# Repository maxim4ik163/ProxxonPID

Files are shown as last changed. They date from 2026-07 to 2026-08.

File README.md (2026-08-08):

# ProxxonPID

Модифицированная версия проекта AlexGyver [DrillPID2](https://github.com/AlexGyver/DrillPID2), адаптированная для **Proxxon Micromot 50/E**.

Проект предназначен для замены штатной платы управления Proxxon Micromot 50/E на собственную плату с функцией поддержания заданной скорости вращения двигателя.

## Основные изменения

* плата разработана с учётом конструкции Proxxon Micromot 50/E и изготавливается в домашних условиях на однослойном текстолите методом ЛУТ;
* изменены `MAX_TARGET_EMF` и `DIV_R2` с учётом питания от 20 В;
* используется родной потенциометр с выключателем;
* добавлен индикатор работы на D13;
* [3D-модель](3D_models/PD_trigger_holder.3mf) крепления PD-триггера;
* проект платы выполнен в Altium Designer.

## Фотографии

### Proxxon Micromot 50/E

<p align="center">
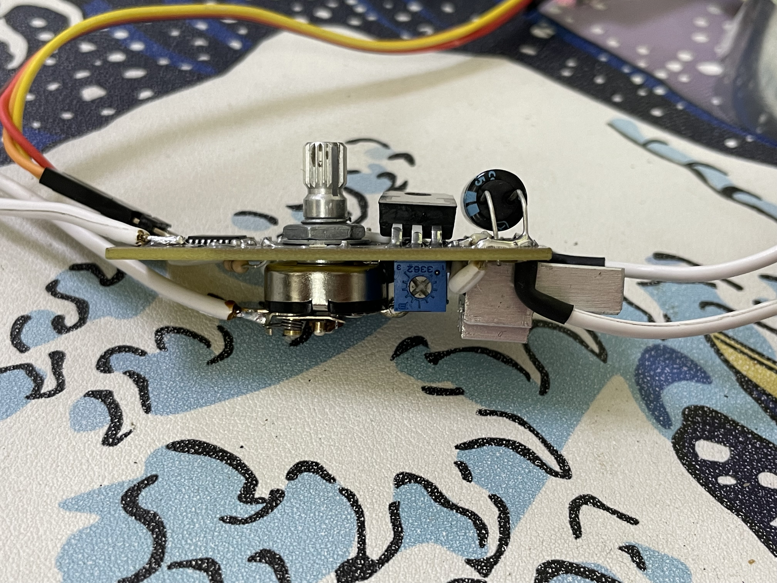
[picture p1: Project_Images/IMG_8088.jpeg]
  
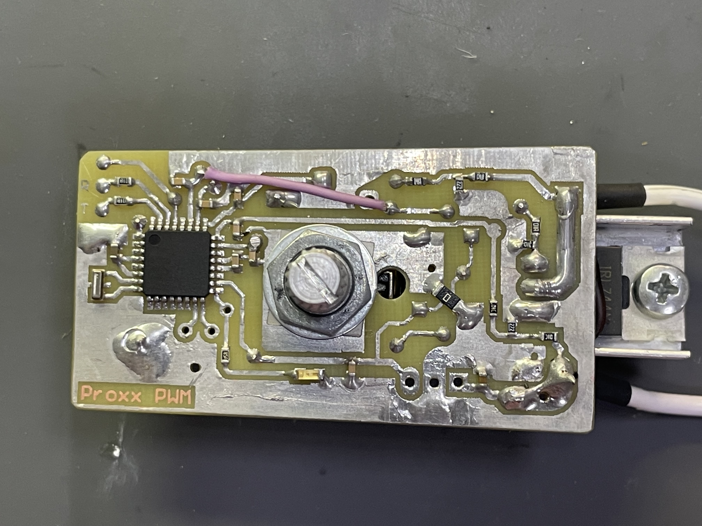
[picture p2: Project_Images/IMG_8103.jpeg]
  
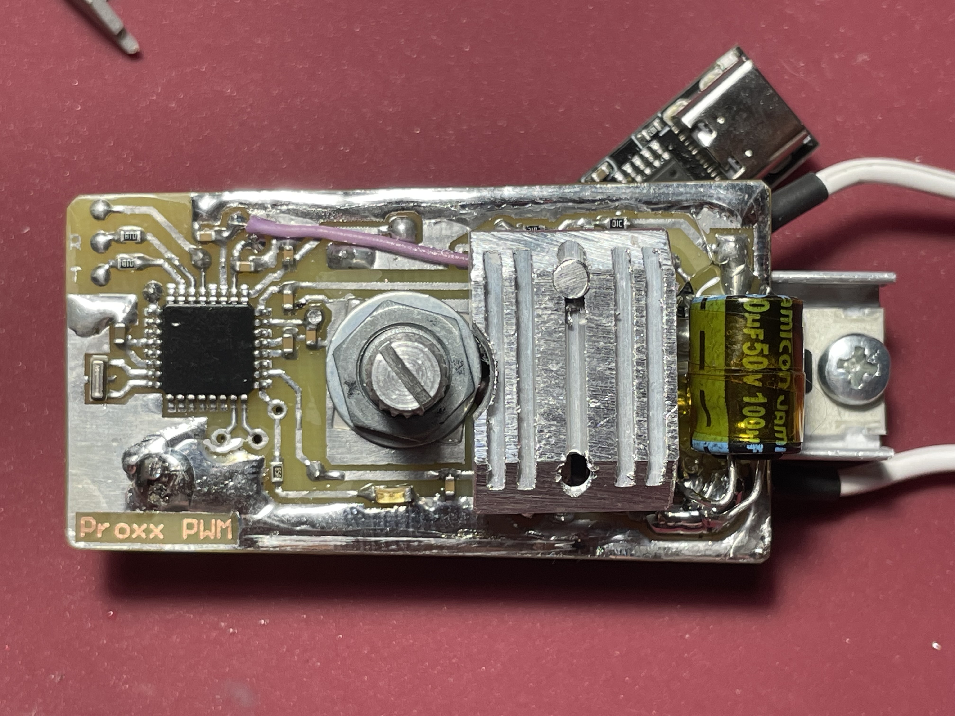
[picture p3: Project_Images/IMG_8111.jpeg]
  
</p>

<p align="center">
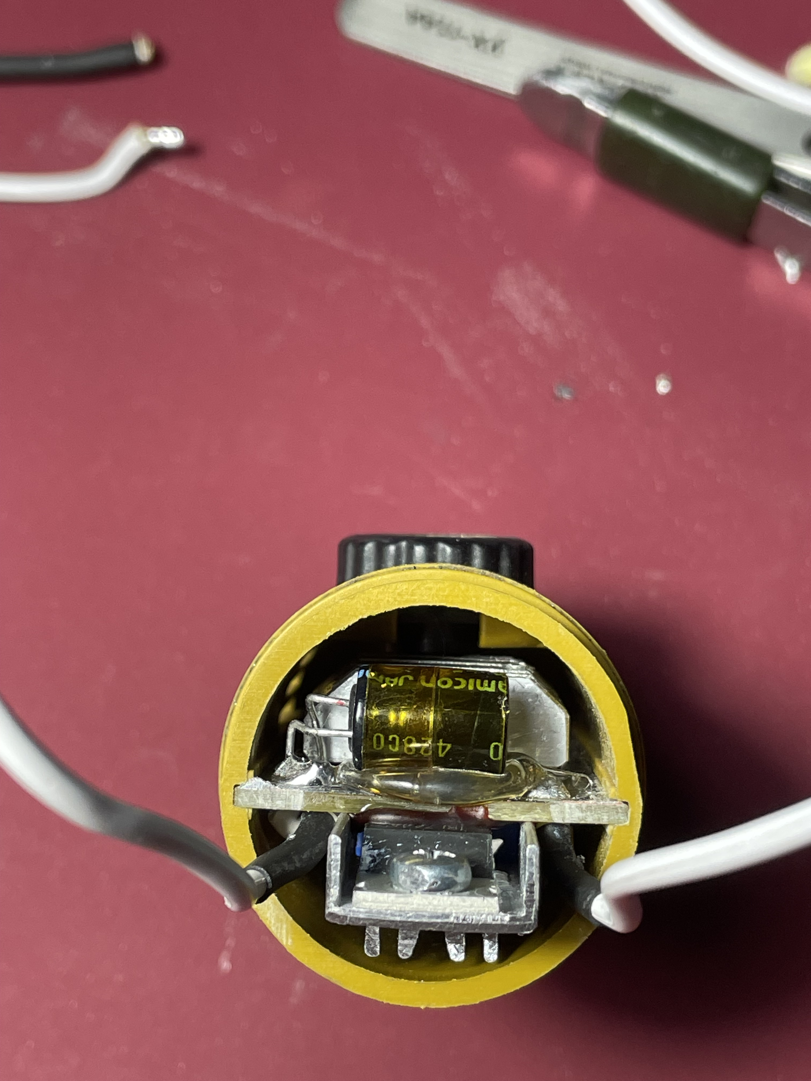
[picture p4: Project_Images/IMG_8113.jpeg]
  
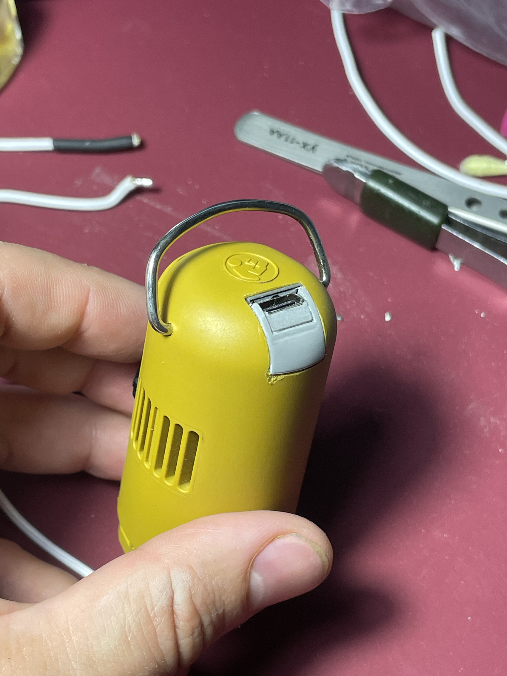
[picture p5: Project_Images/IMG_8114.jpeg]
  
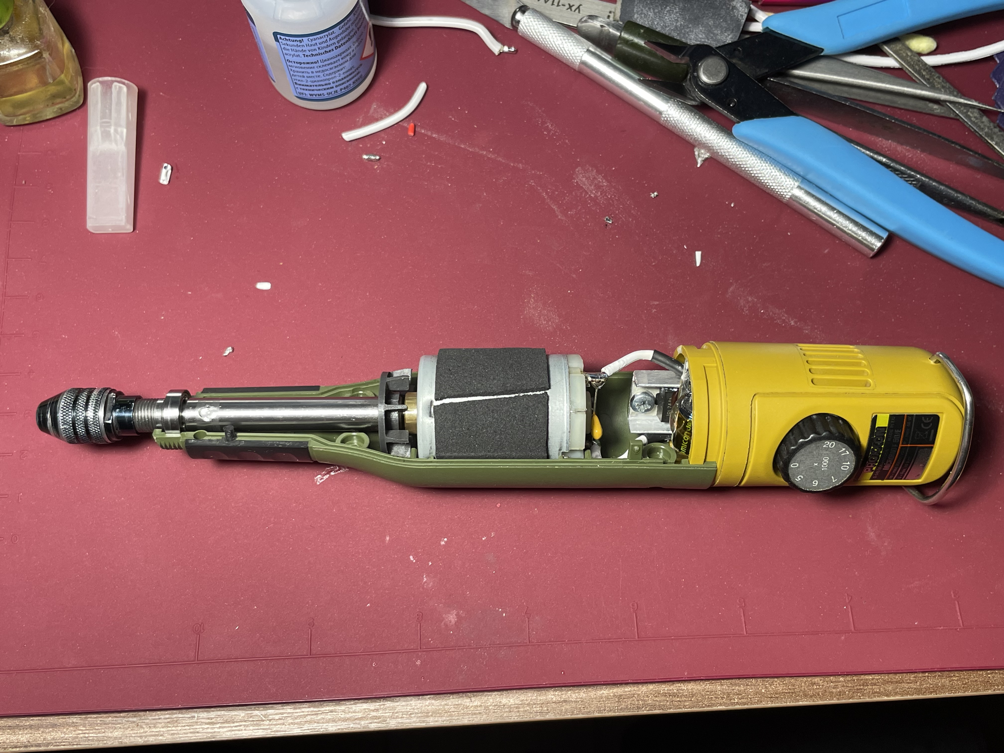
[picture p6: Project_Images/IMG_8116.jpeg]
  
</p>

### Штатная плата

<p align="center">
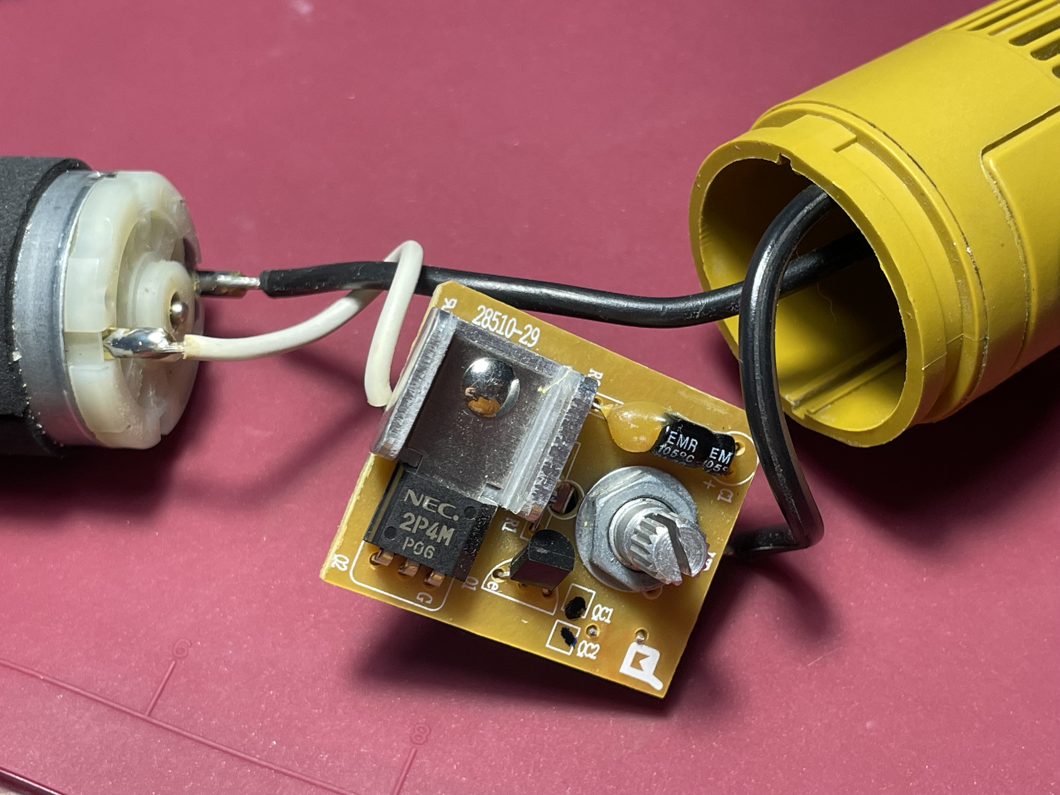
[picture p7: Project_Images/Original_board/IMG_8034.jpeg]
  
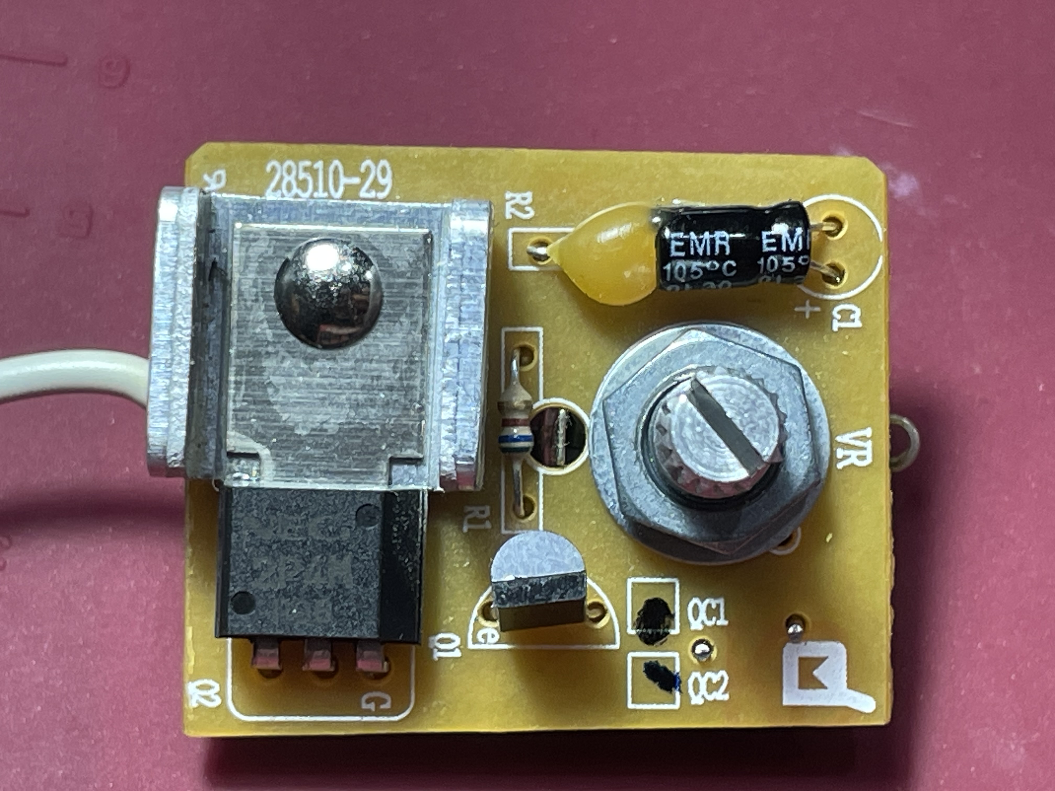
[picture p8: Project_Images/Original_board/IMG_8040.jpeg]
  
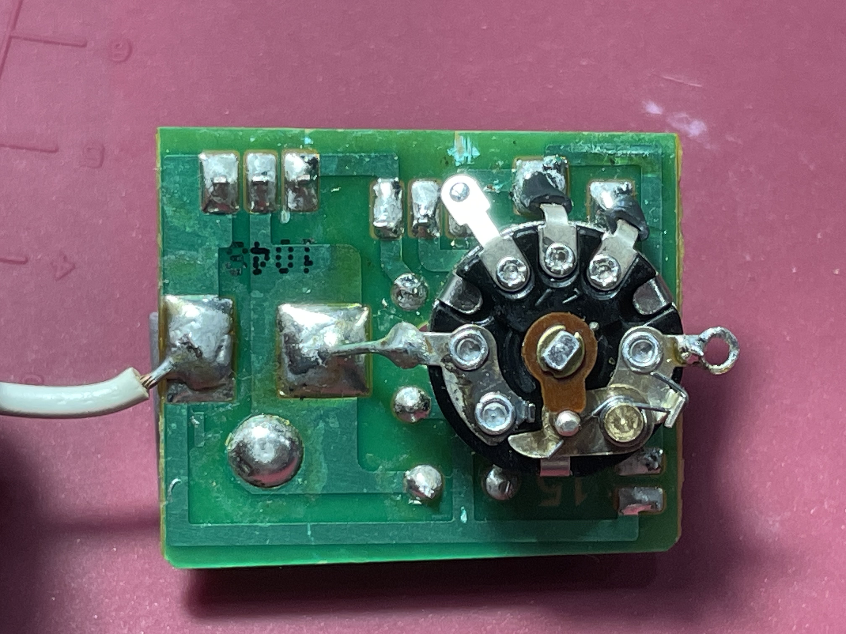
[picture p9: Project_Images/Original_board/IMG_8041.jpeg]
  
</p>

### PD-триггер

<p align="center">
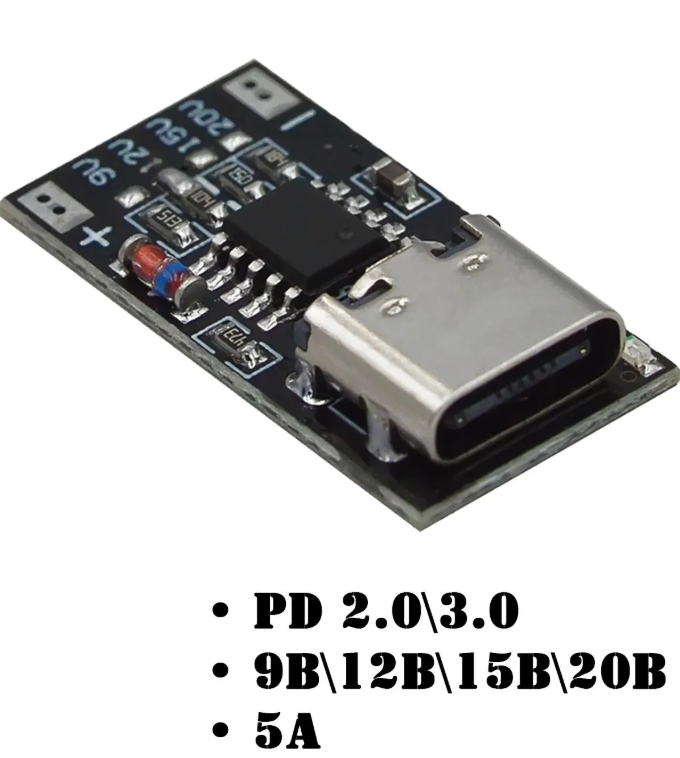
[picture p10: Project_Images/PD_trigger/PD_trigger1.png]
  
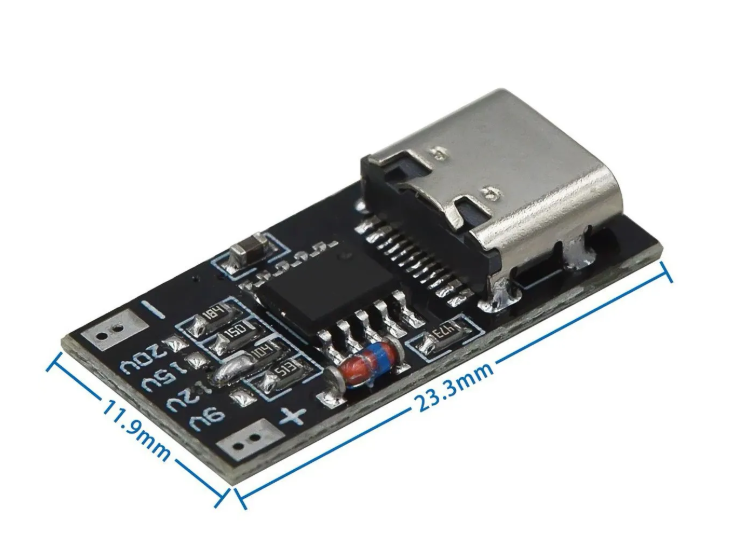
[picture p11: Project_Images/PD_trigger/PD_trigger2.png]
  
</p>

## Проект платы

Исходные файлы печатной платы находятся в каталоге [`PCB`](Altium_project/Proxxon_PWM_board).

Проект выполнен в **Altium Designer 25**.

## Прошивка

Прошивка для **Arduino Nano** находится в каталоге [`Firmware`](firmware/DrillPID2).

## Disclaimer

Проект предназначен для самостоятельного изготовления и модификации оборудования.

Использование проекта осуществляется на свой страх и риск. Автор не несёт ответственности за повреждение инструмента, электроники или иного оборудования в результате использования данной разработки.

---

# English

# ProxxonPID

A modified version of the AlexGyver [DrillPID2](https://github.com/AlexGyver/DrillPID2) project, adapted for the **Proxxon Micromot 50/E**.

The project is intended to replace the original control board of the Proxxon Micromot 50/E with a custom control board featuring **constant speed control**.

## Main Changes

* PCB designed specifically for the Proxxon Micromot 50/E and suitable for home manufacturing on single-sided PCB material using the toner transfer method;
* `MAX_TARGET_EMF` and `DIV_R2` values modified for a 20 V power supply;
* the original potentiometer with an integrated switch is retained;
* an operation indicator has been added to D13;
* [3D model](3D_models/PD_trigger_holder.3mf) of the PD trigger holder;
* PCB project designed in Altium Designer.

## Photos

### Proxxon Micromot 50/E

<p align="center">
  
  
  
</p>

<p align="center">
  
  
  
</p>

### Original Control Board

<p align="center">
  
  
  
</p>

### PD Trigger

<p align="center">
  
  
</p>

## PCB Project

The PCB source files are located in the [`PCB`](Altium_project/Proxxon_PWM_board) directory.

The project was designed using **Altium Designer 25**.

## Firmware

The **Arduino Nano** firmware is located in the [`Firmware`](firmware/DrillPID2) directory.

## Disclaimer

This project is intended for DIY manufacturing and modification of equipment.

Use this project at your own risk. The author is not responsible for any damage to the tool, electronics, or other equipment resulting from the use of this project.

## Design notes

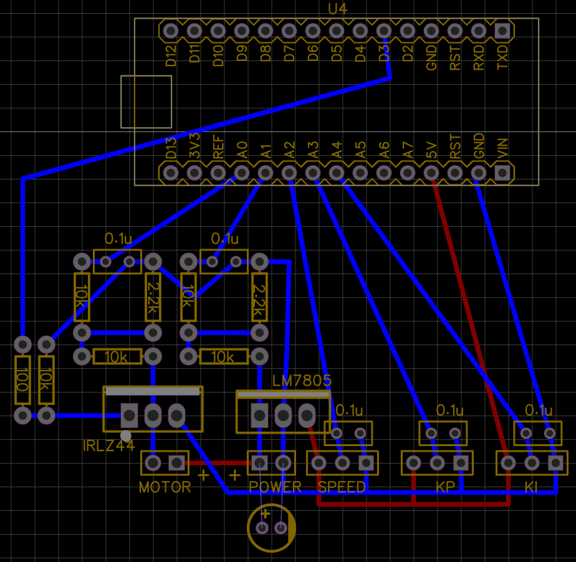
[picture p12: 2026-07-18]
scheme_and_LUTpcb/Original_board.png

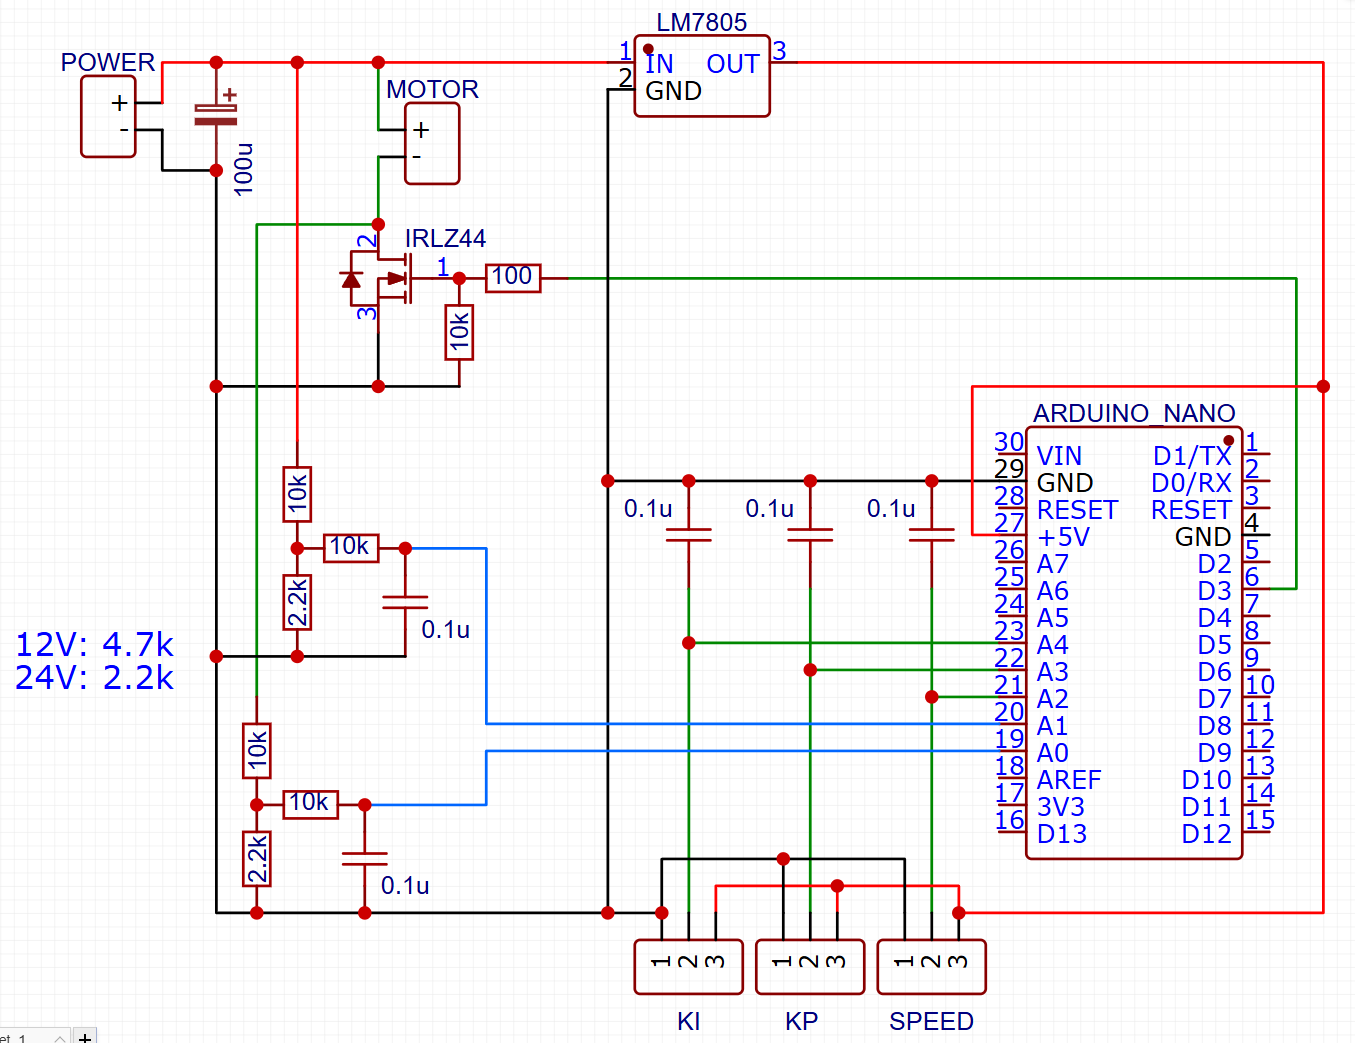
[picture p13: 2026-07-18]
scheme_and_LUTpcb/Original_scheme-eda.png

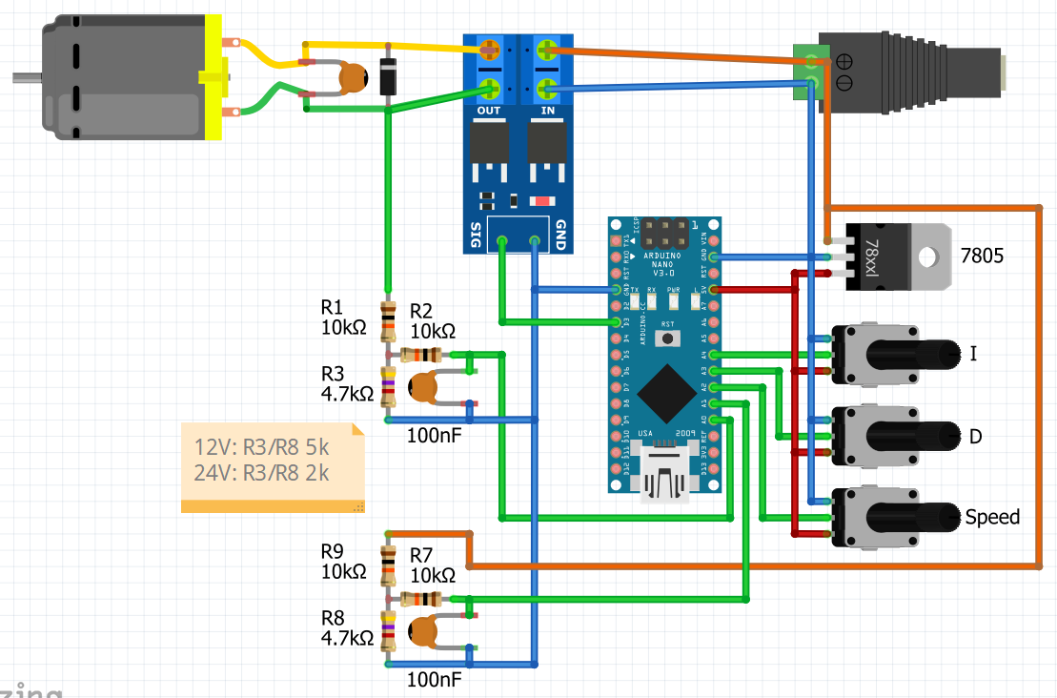
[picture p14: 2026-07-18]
scheme_and_LUTpcb/Original_scheme.png

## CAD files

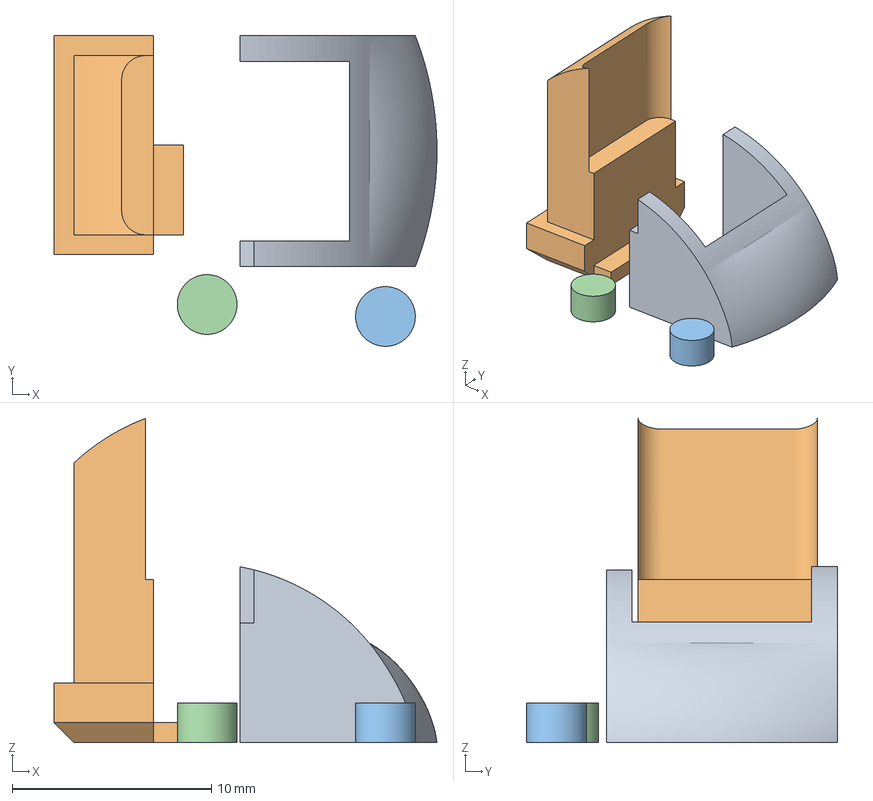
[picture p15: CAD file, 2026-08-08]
3D_models/PD_trigger_holder.3mf
19.2 x 15.6 x 16.3 mm
socket1
socket2

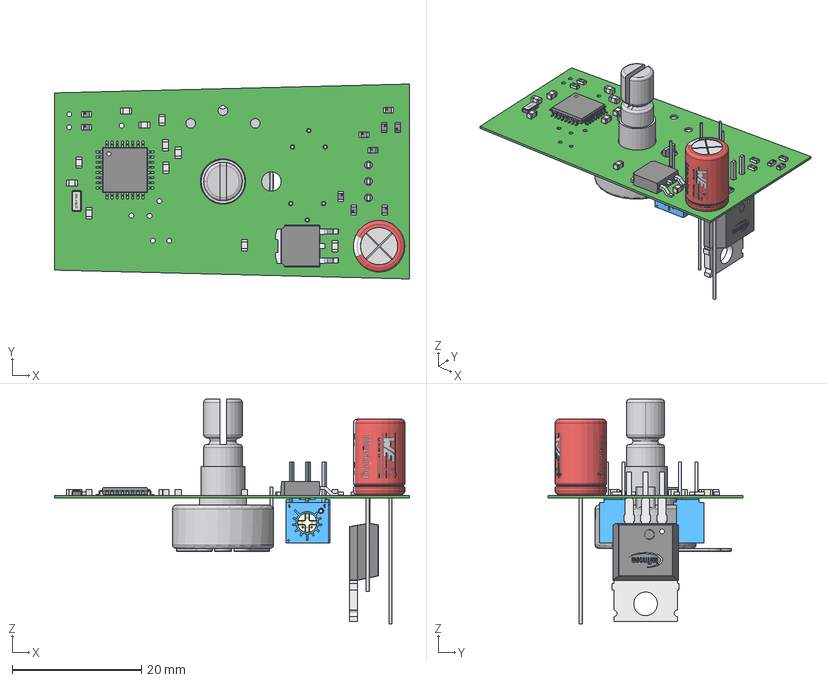
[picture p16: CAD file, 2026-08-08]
Altium_project/Proxxon_PWM_board/PCB_Proxxon_PWM.step
55.0 x 30.2 x 34.8 mm
Pins
Cover
VR
L7805CDT-TR_L7805CDT-TR
terminals x 10
logo x 11
top x 10
pins
Body001 (Mirror #1) x 8
Body002 (Mirror #2) x 8
XY-plane x 15
X-axis x 15
Extruded x 33
8x11.5x3.5x0.5 x 3

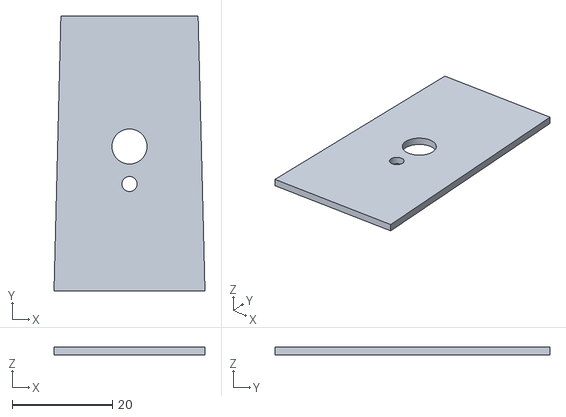
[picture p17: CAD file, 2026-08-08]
3D_models/Proxxon_pcb_template.stl
30.2 x 55.0 x 1.50

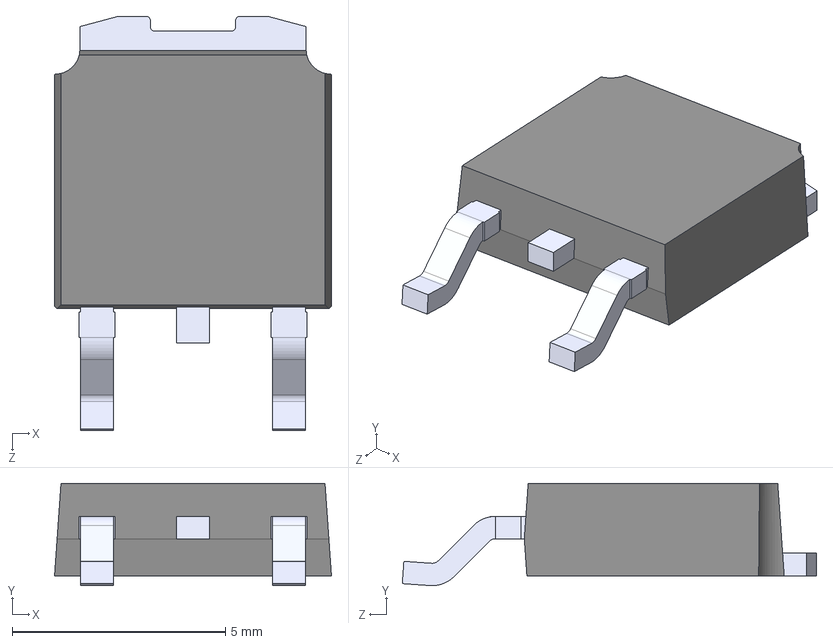
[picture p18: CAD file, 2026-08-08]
Altium_project/Proxxon_PWM_board/L7805CDTTR.STEP
6.50 x 2.40 x 9.72 mm

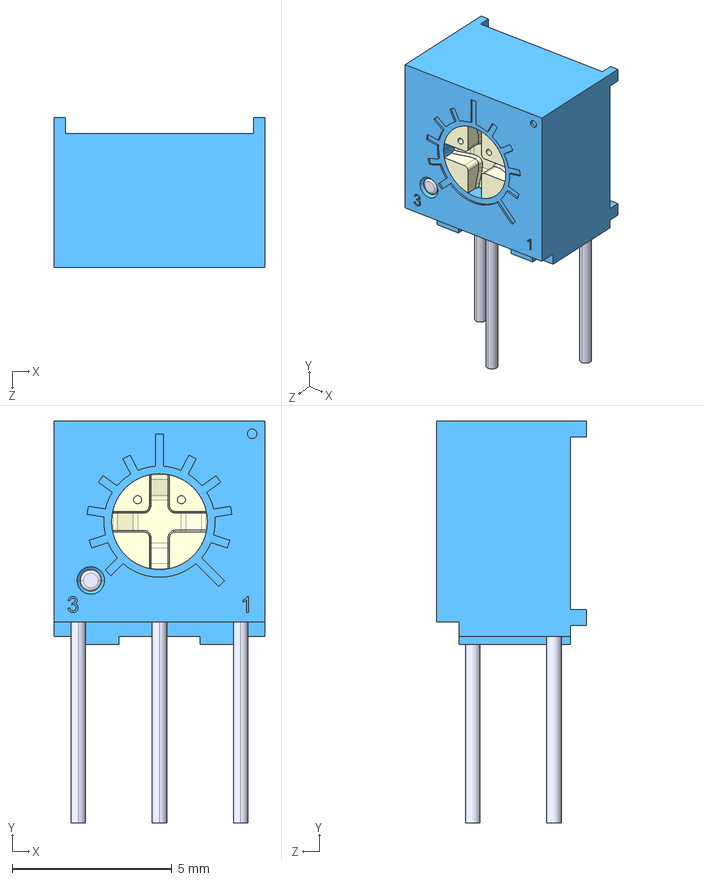
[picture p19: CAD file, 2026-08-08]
Altium_project/Proxxon_PWM_board/3362W-1-203LF--3DModel-STEP-56544.STEP
6.60 x 12.6 x 4.70 mm

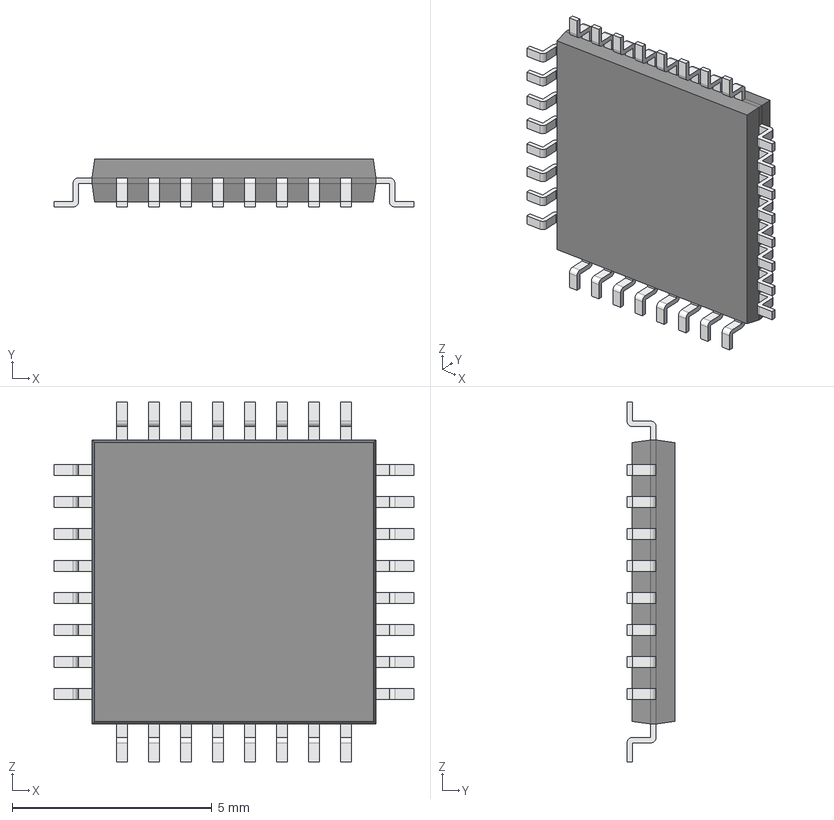
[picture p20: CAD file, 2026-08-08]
Altium_project/Proxxon_PWM_board/ATMEGA328PBAU--3DModel-STEP-510211.STEP
9.00 x 1.20 x 9.00 mm
Body001 (Mirror #1) x 8
Body002 (Mirror #2) x 8
XY-plane x 15
X-axis x 15

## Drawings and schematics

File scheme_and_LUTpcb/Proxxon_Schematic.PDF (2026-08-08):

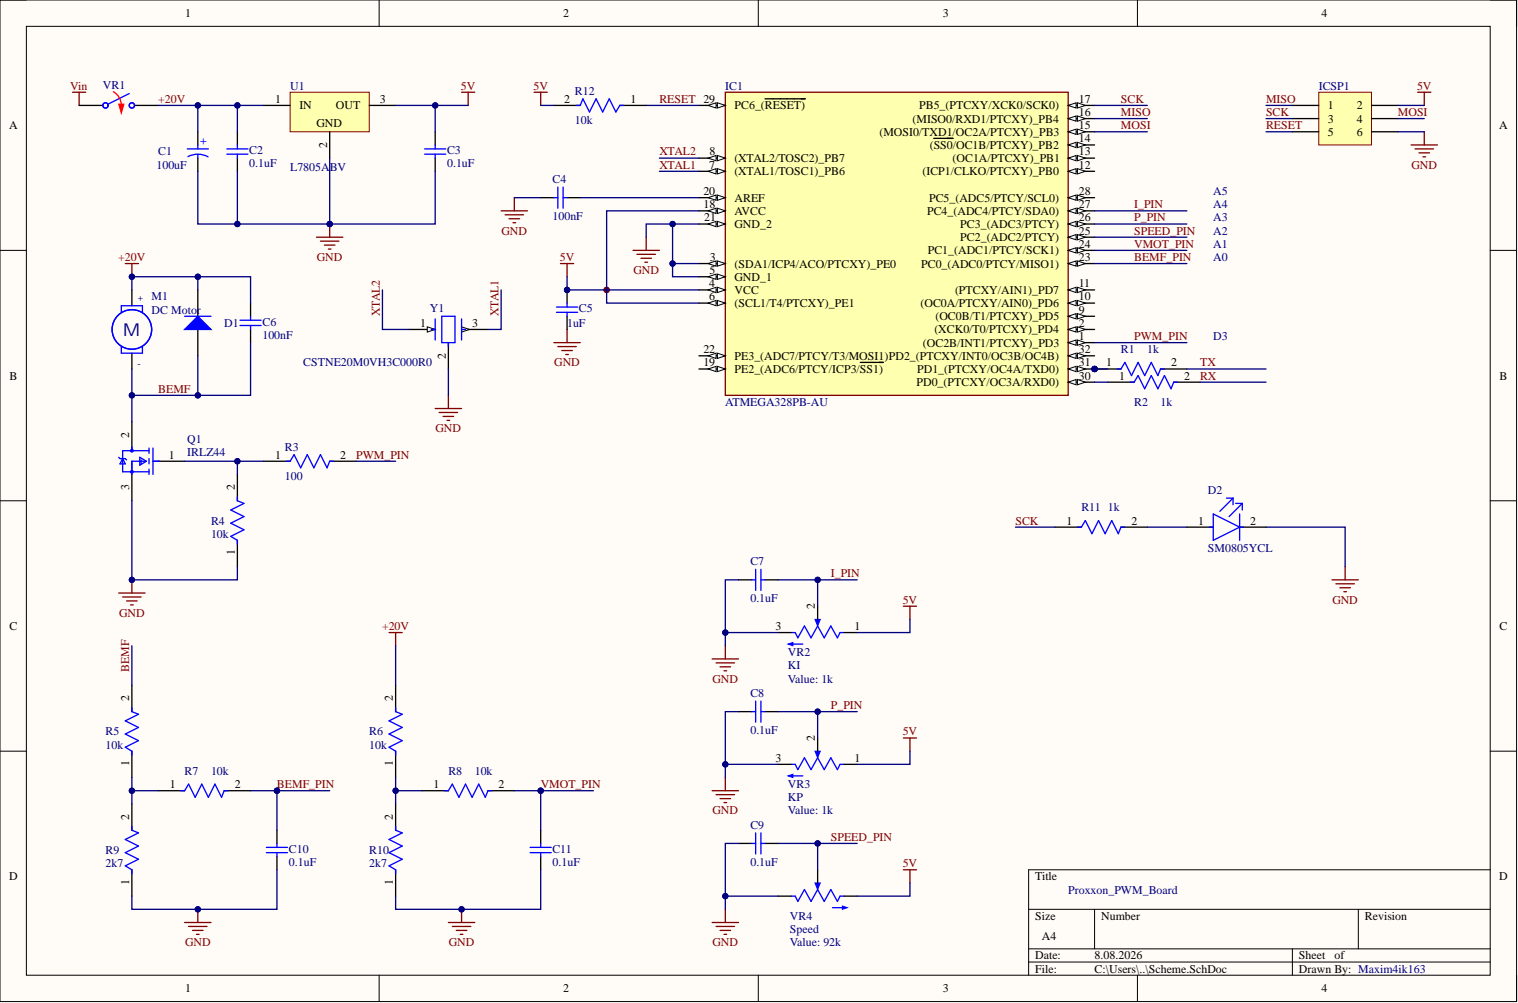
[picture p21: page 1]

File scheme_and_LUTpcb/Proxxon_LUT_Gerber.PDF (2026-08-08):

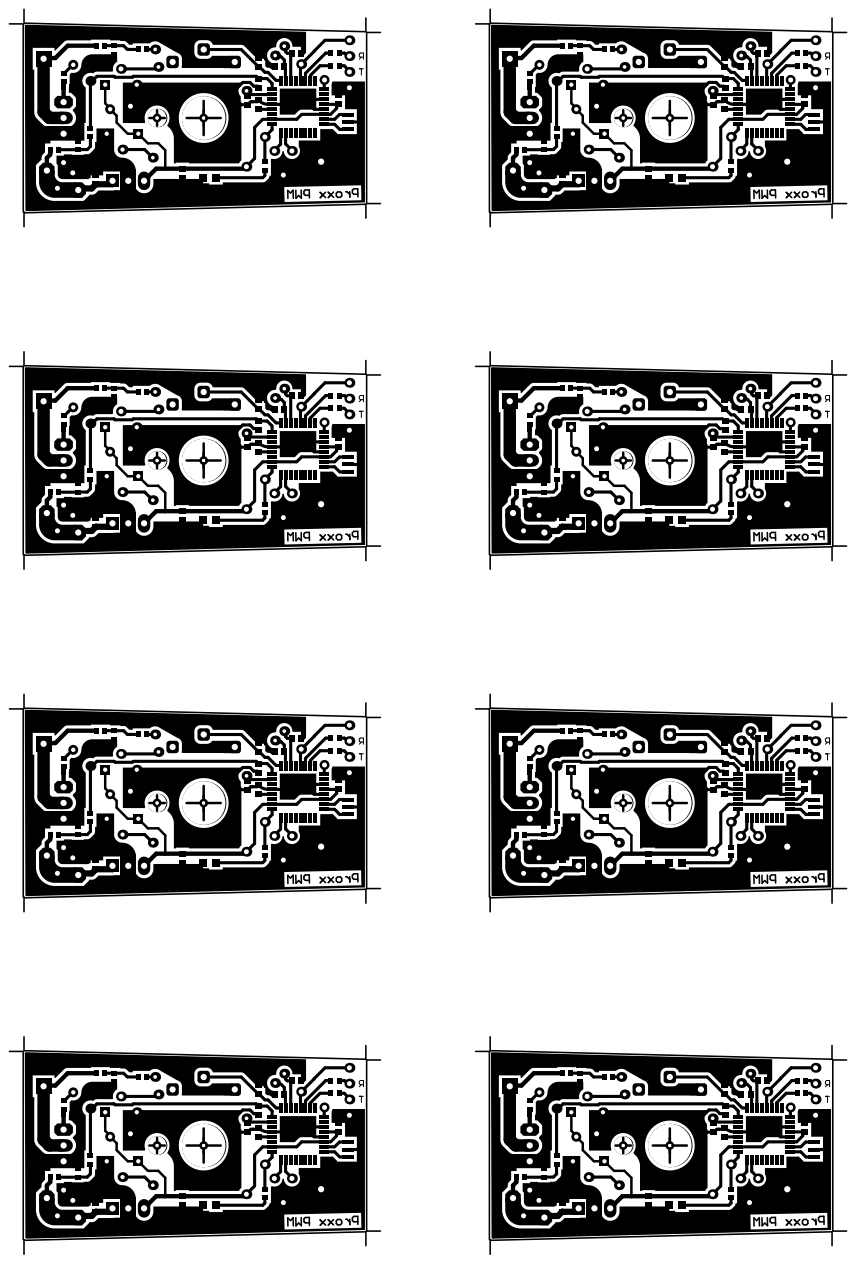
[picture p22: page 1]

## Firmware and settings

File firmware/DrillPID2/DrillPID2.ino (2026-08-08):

#include <Arduino.h>

// =========================== CONFIG ===========================
#define MAX_TARGET_EMF 15500  // для proxxon Vmax=18V. максимальный целевой BEMF [мВ] 
#define DIV_R1 10000          // верхнее плечо делителя [Ом]
#define DIV_R2 2700           // нижнее плечо делителя [Ом] для Vin=20V
#define PID_DIVIDER 4000.0    // делитель коэффициентов (выход ацп 0-1023 делится на него)

// system
#define MIN_TARGET_EMF 200  // минимальный целевой BEMF [мВ]
#define REF1_1 1100         // напряжение опорного 1.1V [мВ]
#define MIN_VMOT 3000       // минимальное питание [мВ]
#define CTRL_PRD 20         // период управления [мс]
#define WAIT_ADC 800        // ожидание после отключения ШИМ [мкс]
#define SMOOTH_STEP 100     // изменение целевой BEMF за период [мВ]

// пины
#define BEMF_PIN A0   // пин измерения BEMF
#define VMOT_PIN A1   // пин измерения питания
#define SPEED_PIN A2  // пин скорости
#define P_PIN A3      // пин P
#define I_PIN A4      // пин I

// =========================== DATA ===========================
int vref;        // реф напряжение
int target = 0;  // таргет emf
int pwm = 0;     // текущий шим

// ========================== IntEMA ==========================
template<typename T>
class IntEMA {
public:
  // k2 - коэффициент как степень двойки
  T filter(T val, uint8_t k2) {
    T sum = (val - _filt) + _err;
    T div = sum >> k2;
    _err = sum - (div << k2);
    return _filt += div;
  }

  void init(T val) {
    _filt = val;
    _err = 0;
  }

  T get() {
    return _filt;
  }

  operator T() {
    return _filt;
  }

private:
  T _filt = 0, _err = 0;
};

IntEMA<int> vmot;
IntEMA<int> vemf;
IntEMA<int> a_tar;
IntEMA<int> a_p;
IntEMA<int> a_i;

// =========================== PIreg ===========================
// ПИ регулятор
class PIreg {
public:
  float Kp = 0;
  float Ki = 0;
  float integral = 0;

  int compute(int input, int setpoint, int feedforward, float dt) {
    float error = setpoint - input;
    float nextIntegral = integral + error * Ki * dt;
    float output = feedforward + error * Kp + nextIntegral;

    if (!((output > 255 && error > 0) || (output < 0 && error < 0))) {
      integral = nextIntegral;
    }

    return constrain(output, 0, 255);
  }
};

PIreg pi;

// =========================== FUNC ===========================

// ШИМ 16 кГц "8 Бит" на пине 3
void setPWM(uint8_t duty) {
  TCCR2A = 1 << COM2B1 | 1 << WGM21 | 1 << WGM20;
  TCCR2B = (1 << WGM22) | 0b010;
  OCR2A = (F_CPU / (16000UL * 8)) - 1;
  if (duty == 0) {
    bitClear(TCCR2A, COM2B1);
    digitalWrite(3, LOW);
  } else {
    bitSet(TCCR2A, COM2B1);
    OCR2B = map(duty, 0, 255, 0, OCR2A);
  }
}

// чтение напряжения питания, мв
uint16_t readVCC(uint16_t ref1v1) {
  uint8_t muxt = ADMUX;
  ADMUX = _BV(REFS0) | _BV(MUX3) | _BV(MUX2) | _BV(MUX1);
  delay(1);
  ADCSRA |= _BV(ADSC);
  while (bit_is_set(ADCSRA, ADSC))
    ;
  uint16_t vcc = ref1v1 * 1023ul / ADC;
  ADMUX = muxt;
  return vcc;
}

// чтение с делителя напряжения, мв
uint16_t readDivider(uint8_t apin) {
  uint32_t pinMv = (uint32_t)analogRead(apin) * vref / 1024;
  return pinMv * (DIV_R1 + DIV_R2) / DIV_R2;
}

// измерение BEFM и управление
void control() {
  static uint32_t tmr;
  if (millis() - tmr < CTRL_PRD) return;
  tmr = millis();

  // измеряем bemf
  setPWM(0);
  delayMicroseconds(WAIT_ADC);

  int rawVmot = readDivider(VMOT_PIN);
  int rawMotor = readDivider(BEMF_PIN);
  int rawBemf = rawVmot - rawMotor;

  // пока считаем математику, возвращаем старый PWM
  if (rawVmot > MIN_VMOT) setPWM(pwm);

  vmot.filter(rawVmot, 2);
  vemf.filter(rawBemf, 2);
  a_tar.filter(1023 - analogRead(SPEED_PIN), 3);
  a_p.filter(1023 - analogRead(P_PIN), 3);
  a_i.filter(1023 - analogRead(I_PIN), 3);

  int newTarget = (long)a_tar.get() * MAX_TARGET_EMF / 1024;

  pi.Kp = a_p.get() / PID_DIVIDER;
  pi.Ki = a_i.get() / PID_DIVIDER;

  if (rawVmot <= MIN_VMOT || newTarget < MIN_TARGET_EMF) {
    pi.integral = 0;
    target = 0;
    pwm = 0;
    setPWM(0);
    return;
  }

  // плавное изменение таргета
  target += constrain(newTarget - target, -SMOOTH_STEP, SMOOTH_STEP);

  // расчётный ШИМ
  int feedforward = (long)target * 255 / vmot.get();

  // ПИД
  pwm = pi.compute(vemf.get(), target, feedforward, CTRL_PRD / 1000.0f);

  setPWM(pwm);
}

// лог
void log() {
  static uint32_t tmr;
  if (millis() - tmr < 100) return;

  tmr = millis();
  Serial.println("#vmot,vemf,tar,pwm10");
  Serial.print('$');
  Serial.print(vmot.get());
  //Serial.print(0);
  Serial.print(',');
  Serial.print(vemf.get());
  //Serial.print(0);
  Serial.print(',');
  Serial.print(target);
  //Serial.print(0);
  Serial.print(',');
  Serial.print(pwm * 10);
  //Serial.print(0);
  Serial.print(',');
  //Serial.print(analogRead(SPEED_PIN));
  Serial.println();
}

void setup() {
  Serial.begin(115200);
  vref = readVCC(REF1_1);
  pinMode(3, OUTPUT);

  pinMode(13, OUTPUT);	 
  digitalWrite(13, HIGH);	//Индикатор работы D13
}

void loop() {
  control();
  log();
}

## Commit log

2026-08-08 Изменения для работы с Proxxon
2026-08-08 Altium project
    [3362W-1-203LF--3DModel-STEP-56544.STEP, 3362W-1-203LF.SchLib, ATMEGA328PB-AU.SchLib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]
2026-08-08 3D models folder
    [PD_trigger_holder.3mf, Proxxon_pcb_template.stl]
2026-08-08 Schematics and PCB
